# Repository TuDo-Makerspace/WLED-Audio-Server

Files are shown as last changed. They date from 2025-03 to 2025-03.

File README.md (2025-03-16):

# WLED Audio Server

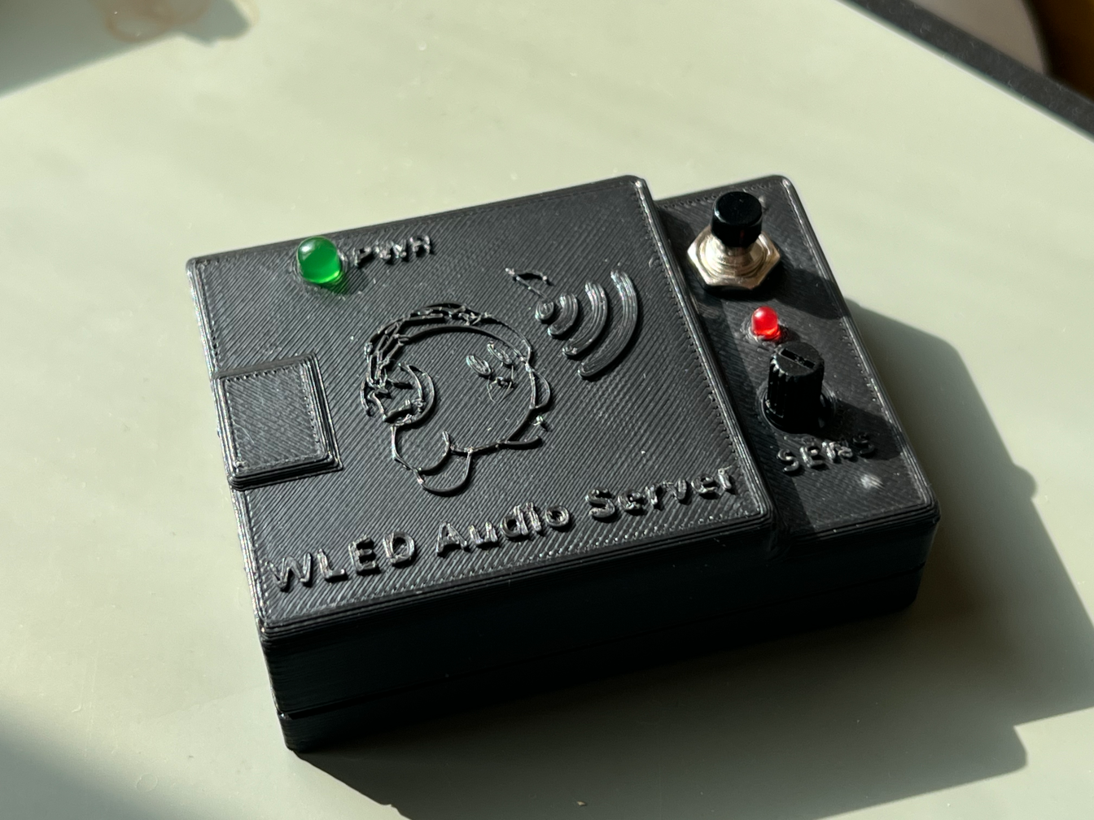
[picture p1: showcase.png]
WLED Audio Server


This compact device is designed to function as a WLED audio server. It analyzes 3.5mm audio input and synchronizes audio-reactive effects across multiple WLED devices using the "Sync" feature. I.e. this is just a "headless" WLED controller.

## Hardware

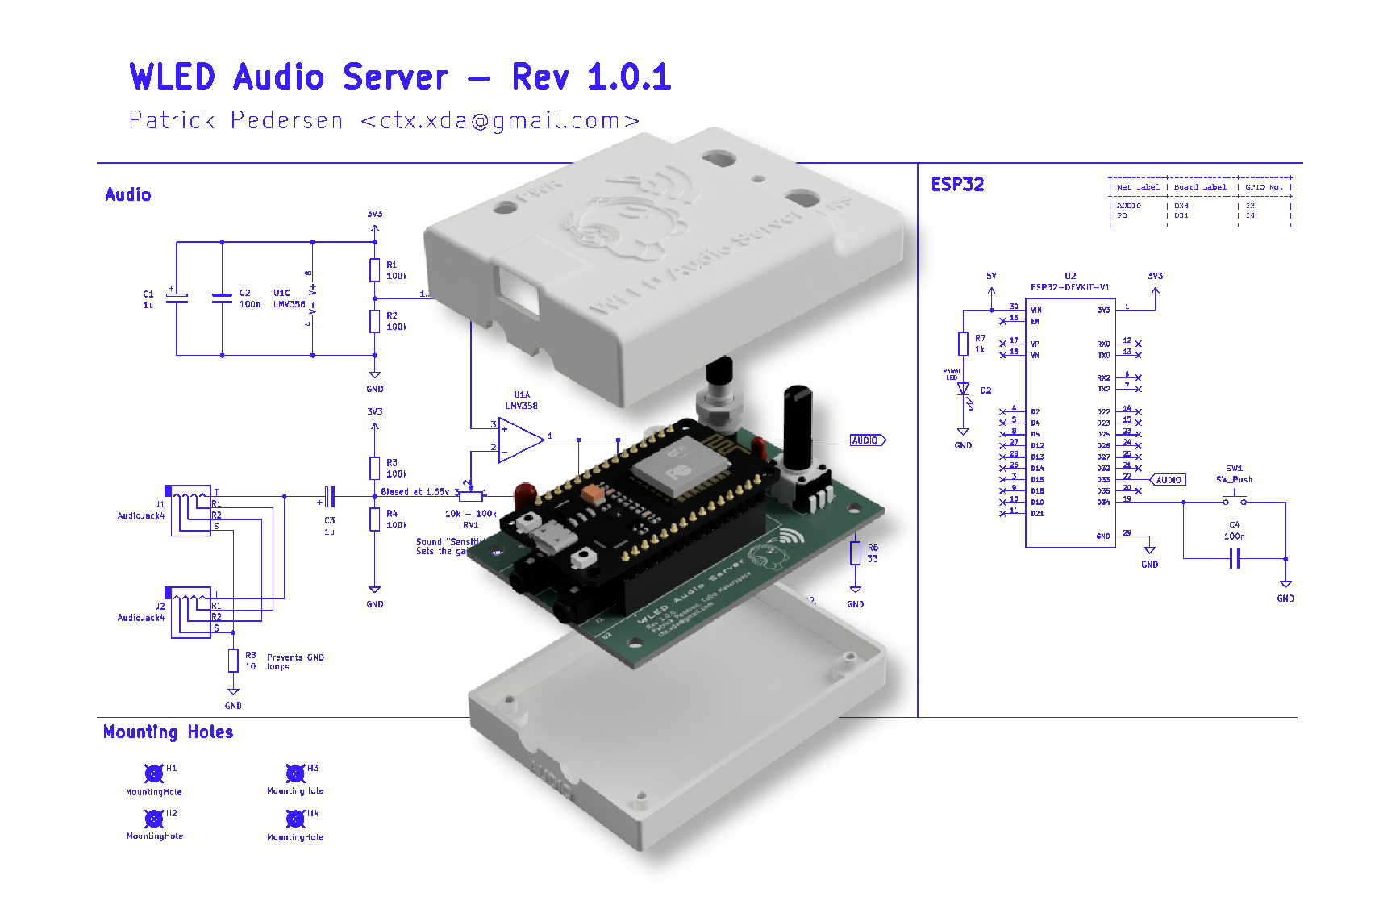
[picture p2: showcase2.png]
Hardware showcase


This device features two 3.5mm audio jacks: one for input and one for through-output (orientation is interchangable). This allows the server to be placed in-line between an audio source and a speaker system.

A potentiometer is used to adjust the gain of the audio input. This lets you amplify quieter signals or reduce the gain for louder ones to clipping. To help with this, a small red clipping LED is included.

Additionally, a push-button is provided, which can be assigned to a specific WLED action, such as changing the effect.

Finally, a power LED is included to indicate when the device is powered on.

The KiCAD files for the Schematic and PCB layout can be found in this repo.

## Firmware

For enhanced audio-reactive capabilities, it is highly recommended to use the **[MoonModules fork of WLED](https://mm.kno.wled.ge/)** on both the audio server and all connected WLED devices. This fork includes additional features and optimizations specifically designed for audio-reactive setups.

A [pre-configured firmware binary](WLED-MM_esp32_4MB_M_14.5.1-dev_preconfigured.bin) for the audio server is available in this repository for quick setup.

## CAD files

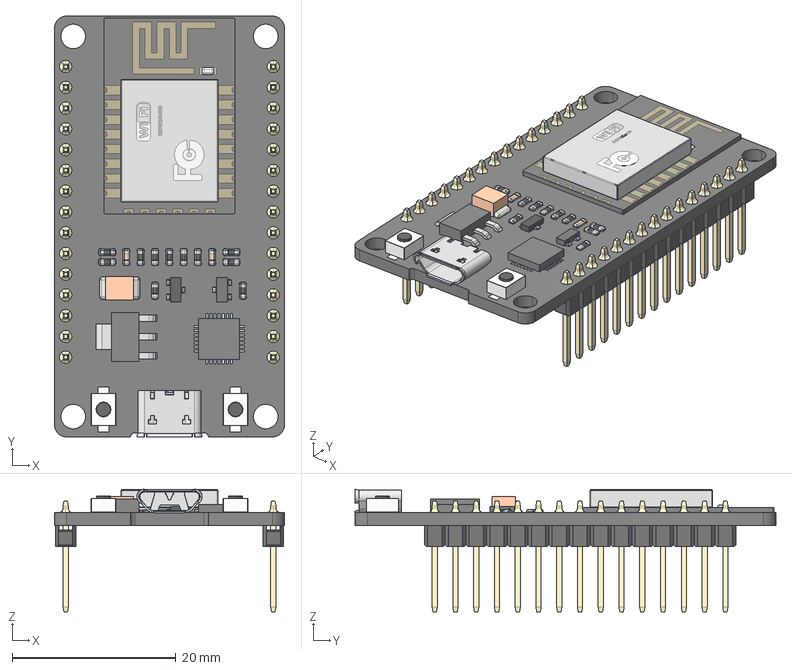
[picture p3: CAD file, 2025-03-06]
3d/esp32_dev_kit_v1_asm.stp
28.1 x 51.5 x 15.0 mm
PCB
PIN x 30
WIFI_CARD_2
RECTANGULARCHIP_2
MICROCHIP_2
TANCHIP_2
TRANSISTOR_3-LEG_2
RESISTOR1_2 x 11
RESISTOR2-32_2 x 2
TRANSISTOR_3-LEG2_2
BUTTONFLASH-13_2 x 2
BUTTONFLASH-14_2 x 2
USB_SOCKET_2

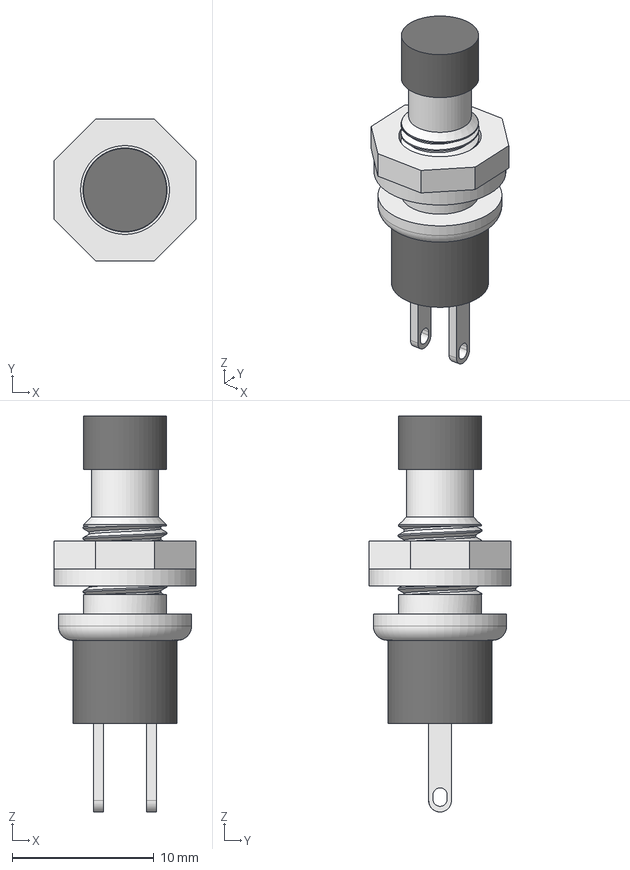
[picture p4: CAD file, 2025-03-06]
3d/Push Button.step
10.0 x 10.0 x 27.9 mm

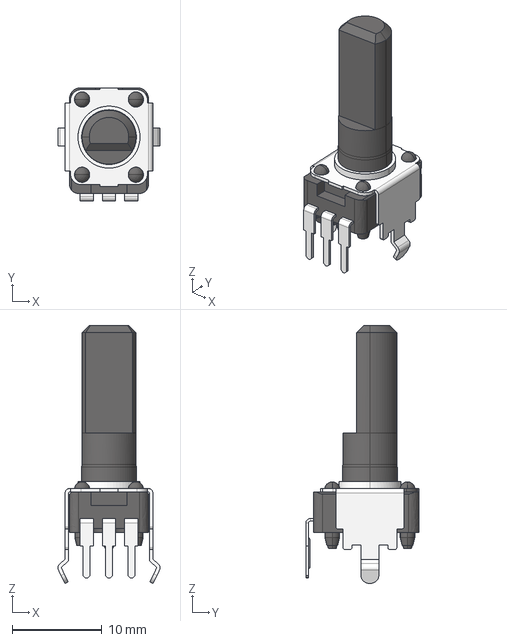
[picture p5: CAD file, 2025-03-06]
3d/RK09K1130AH1.STEP
11.4 x 12.7 x 28.8 mm

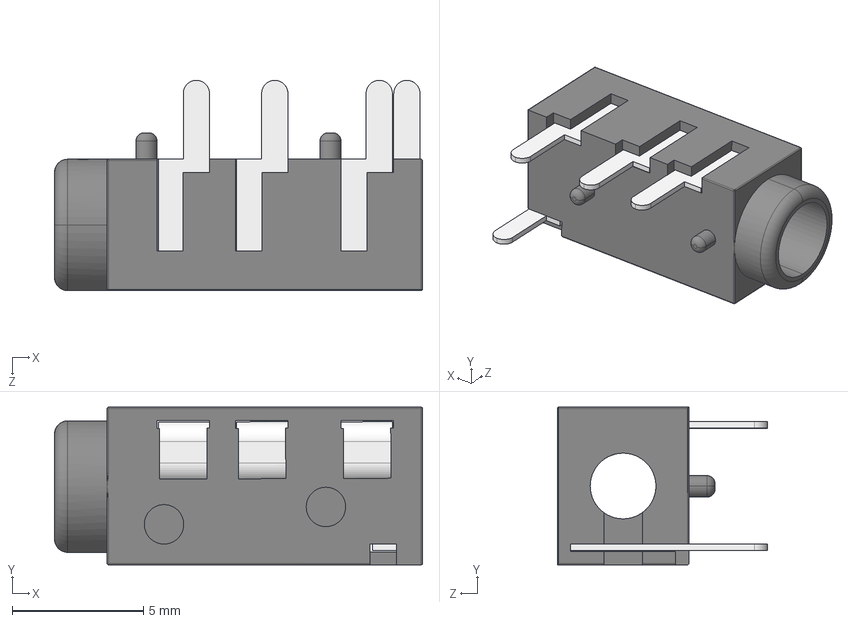
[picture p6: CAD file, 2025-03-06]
3d/PJ320A.STEP
14.0 x 6.00 x 8.00 mm
PJ320A
PJ320A-Pin x 3
PJ320A-Pin-B

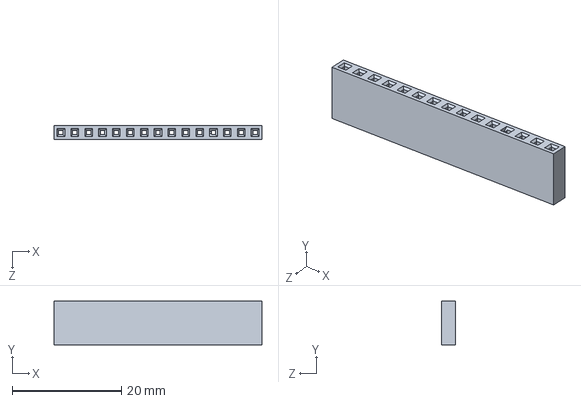
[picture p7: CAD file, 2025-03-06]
3d/Header_Female_single_15.STEP
38.1 x 8.00 x 2.50 mm

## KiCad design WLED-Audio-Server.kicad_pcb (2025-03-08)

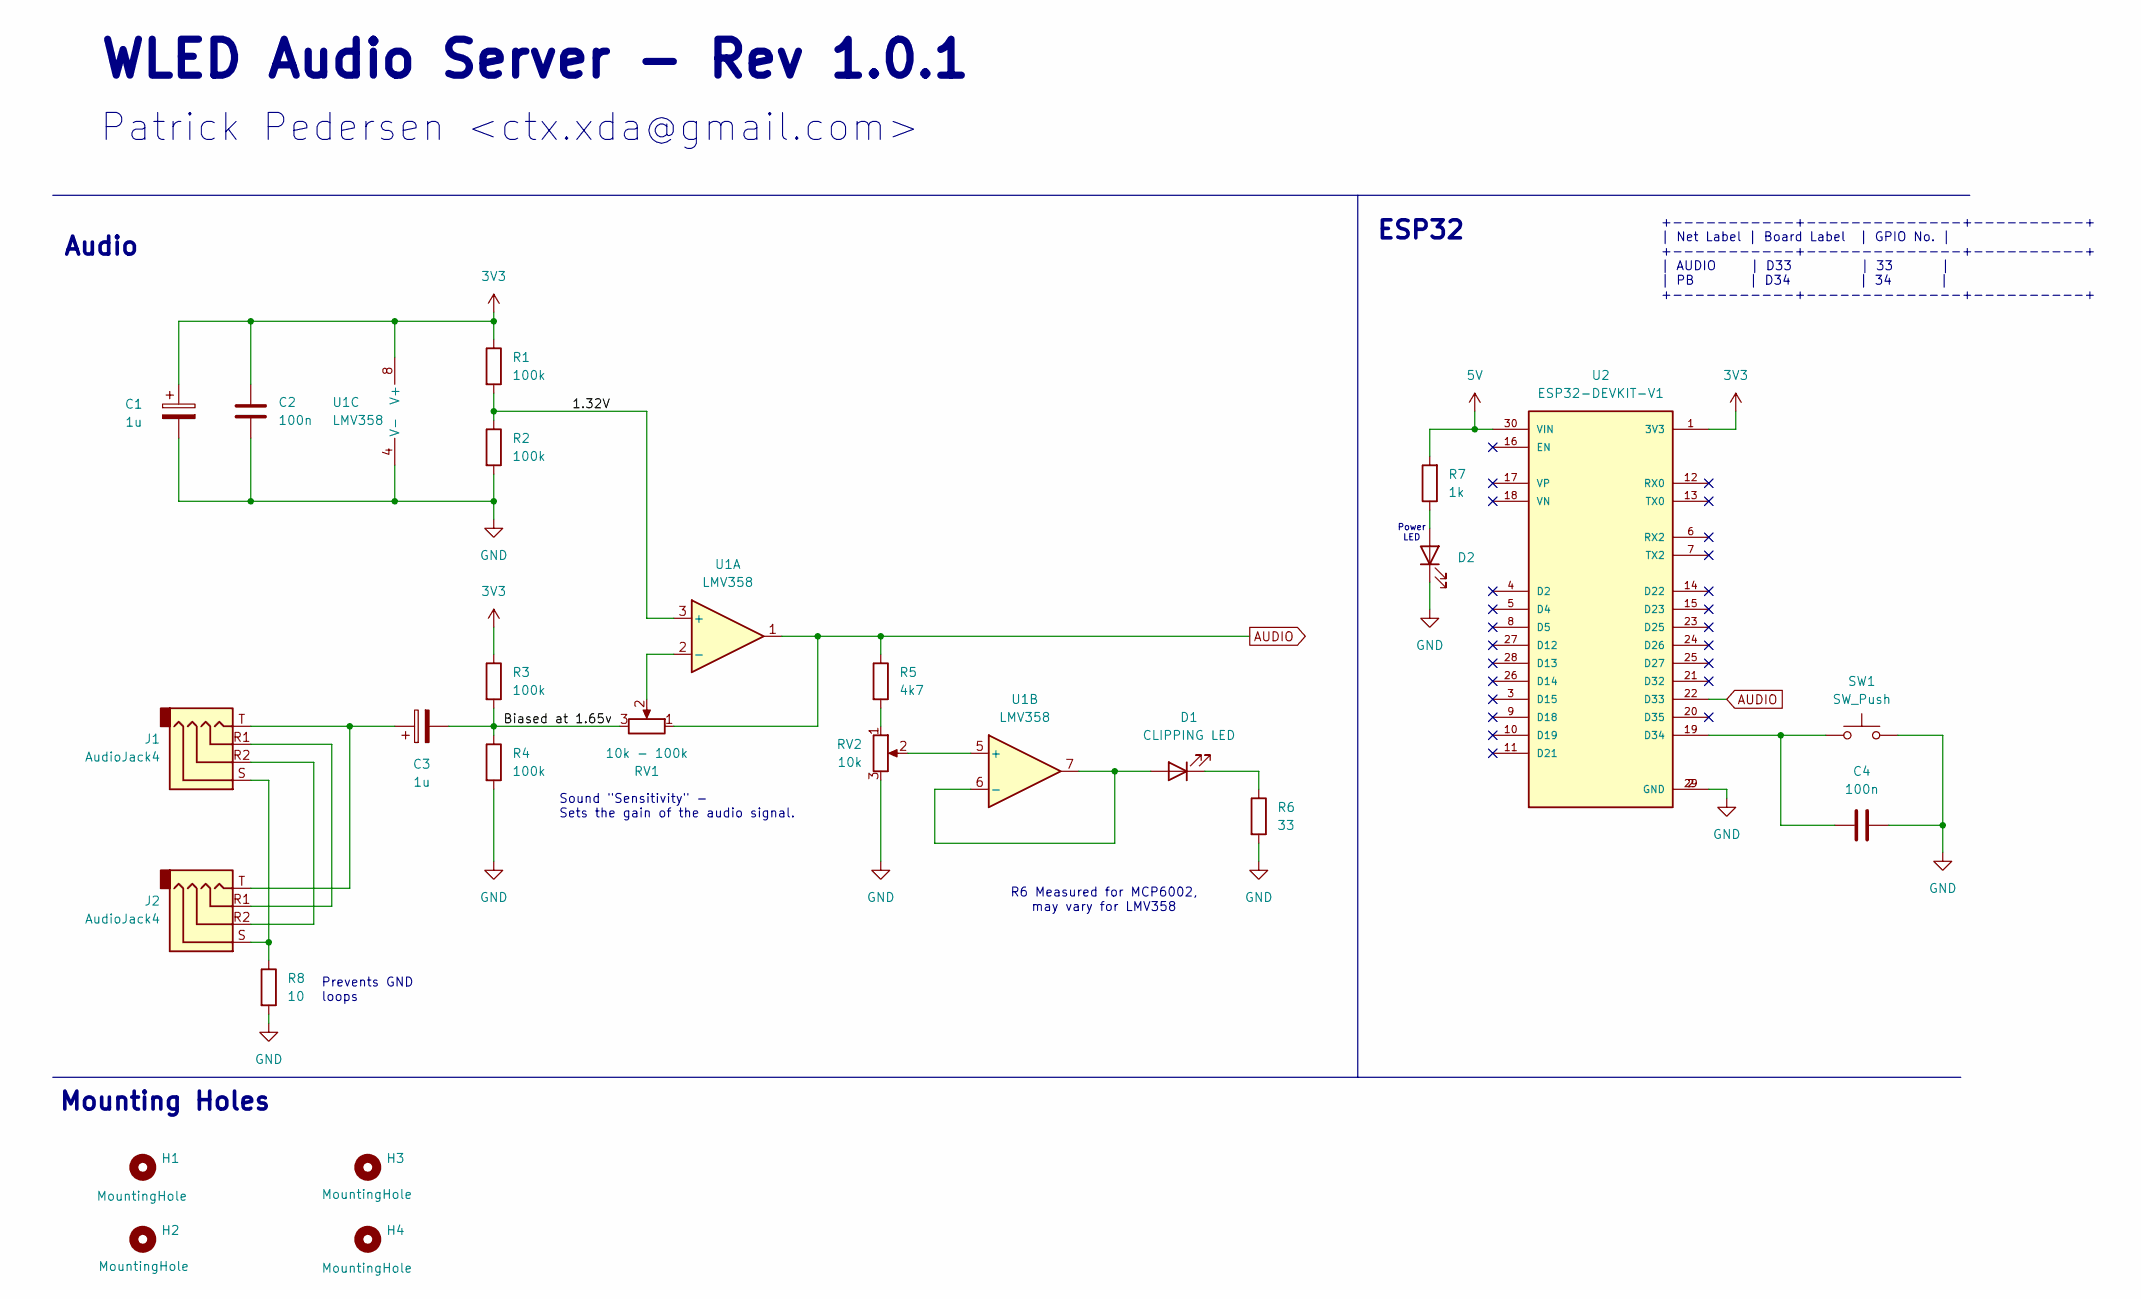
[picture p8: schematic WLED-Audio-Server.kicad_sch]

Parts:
C1, C3: 1u; CP_Radial_D4.0mm_P2.00mm
C2, C4: 100n; C_1206_3216Metric_Pad1.33x1.80mm_HandSolder
D1: CLIPPING LED; LED_D3.0mm
D2: LED; LED_D5.0mm
H1, H2, H3, H4: MountingHole; MountingHole_3.2mm_M3
J1, J2: AudioJack4; TRRS-PJ-320A
R1, R2, R3, R4: 100k; R_1206_3216Metric_Pad1.30x1.75mm_HandSolder
R5: 4k7; R_1206_3216Metric_Pad1.30x1.75mm_HandSolder
R6: 33; R_1206_3216Metric_Pad1.30x1.75mm_HandSolder
R7: 1k; R_1206_3216Metric_Pad1.30x1.75mm_HandSolder
R8: 10; R_1206_3216Metric_Pad1.30x1.75mm_HandSolder
RV1: 10k - 100k; Potentiometer_RV09
RV2: 10k; Potentiometer_Runtron_RM-065_Vertical
SW1: SW_Push; SW_Push_ThroughHole_2Pin_7mm
U1: LMV358; SOIC-8_3.9x4.9mm_P1.27mm
U2: ESP32-DEVKIT-V1; MODULE_ESP32_DEVKIT_V1; PARTREV N/A

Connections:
3V3: C1.1, C2.2, R1.1, R3.1, U1.8 (V+), U2.1 (3V3)
5V: R7.2, U2.30 (VIN)
/1.32V: R1.2, R2.1, U1.3 (+)
/Biased at 1.65v: C3.2, R3.2, R4.1, RV1.3
AUDIO: R5.1, RV1.1, U1.1, U2.22 (D33)
GND: C1.2, C2.1, C4.2, D2.1 (K), R2.2, R4.2, R6.2, R8.2, RV2.3, SW1.2, U1.4 (V-), U2.2 (GND), U2.29 (GND)
unnamed: C3.1, J1.T, J2.T
unnamed: D1.2 (A), U1.6 (-), U1.7
unnamed: D1.1 (K), R6.1
unnamed: D2.2 (A), R7.1
unnamed: J1.R1, J2.R1
unnamed: J1.R2, J2.R2
unnamed: J1.S, J2.S, R8.1
unnamed: R5.2, RV2.1
unnamed: RV1.2, U1.2 (-)
unnamed: RV2.2, U1.5 (+)
unnamed: C4.1, SW1.1, U2.19 (D34)

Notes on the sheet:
Patrick Pedersen <ctx.xda@gmail.com>
Audio
Mounting Holes
ESP32
Prevents GND loops
Sound "Sensitivity" - Sets the gain of the audio signal.
R6 Measured for MCP6002, may vary for LMV358
Power LED
+-----------+--------------+----------+ | Net Label | Board Label | GPIO No. | +-----------+--------------+----------+ | AUDIO | D33 | 33 | | PB | D34 | 34 | +-----------+--------------+----------+
WLED Audio Server - Rev 1.0.1

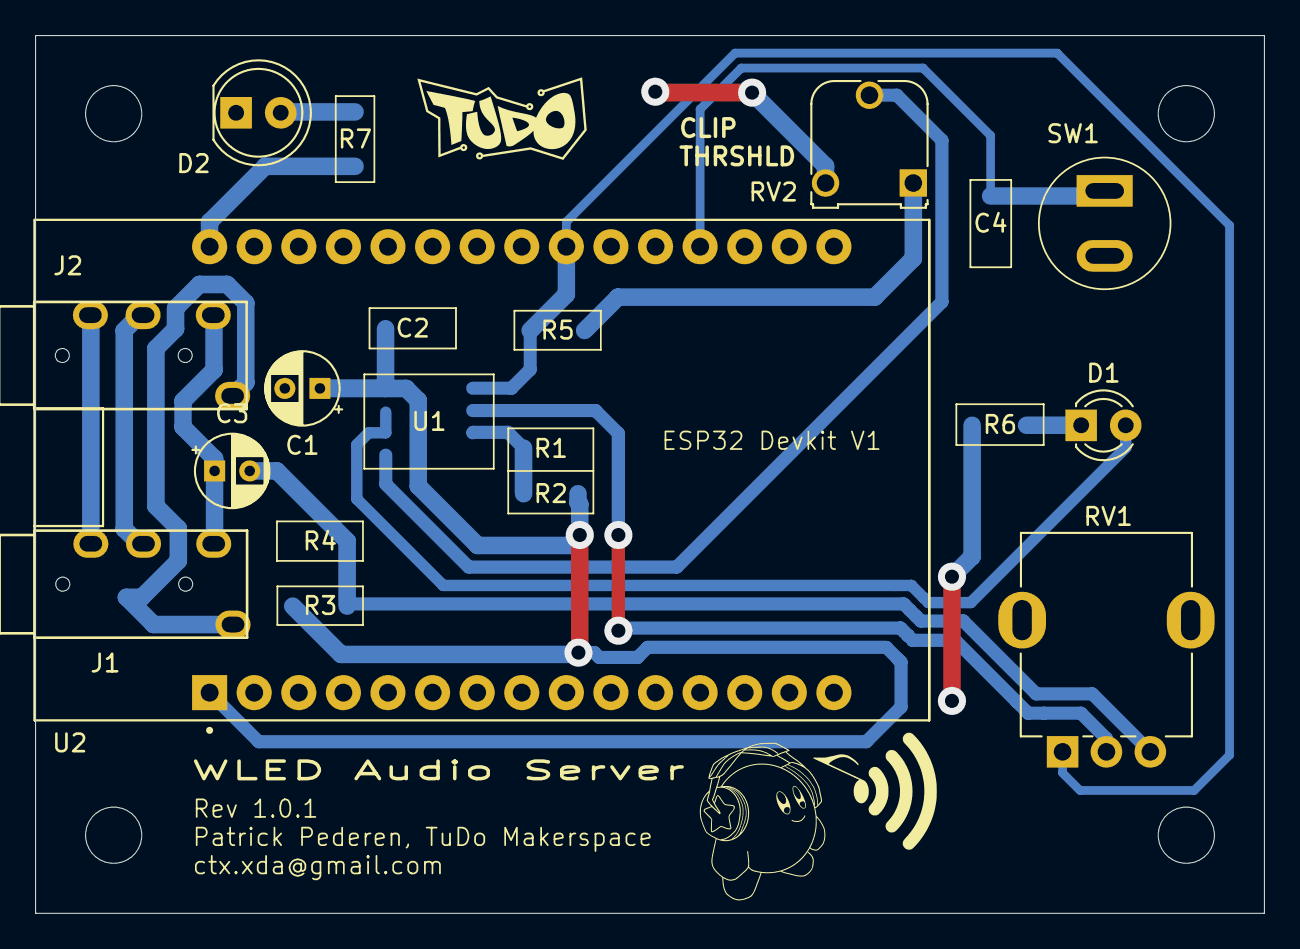
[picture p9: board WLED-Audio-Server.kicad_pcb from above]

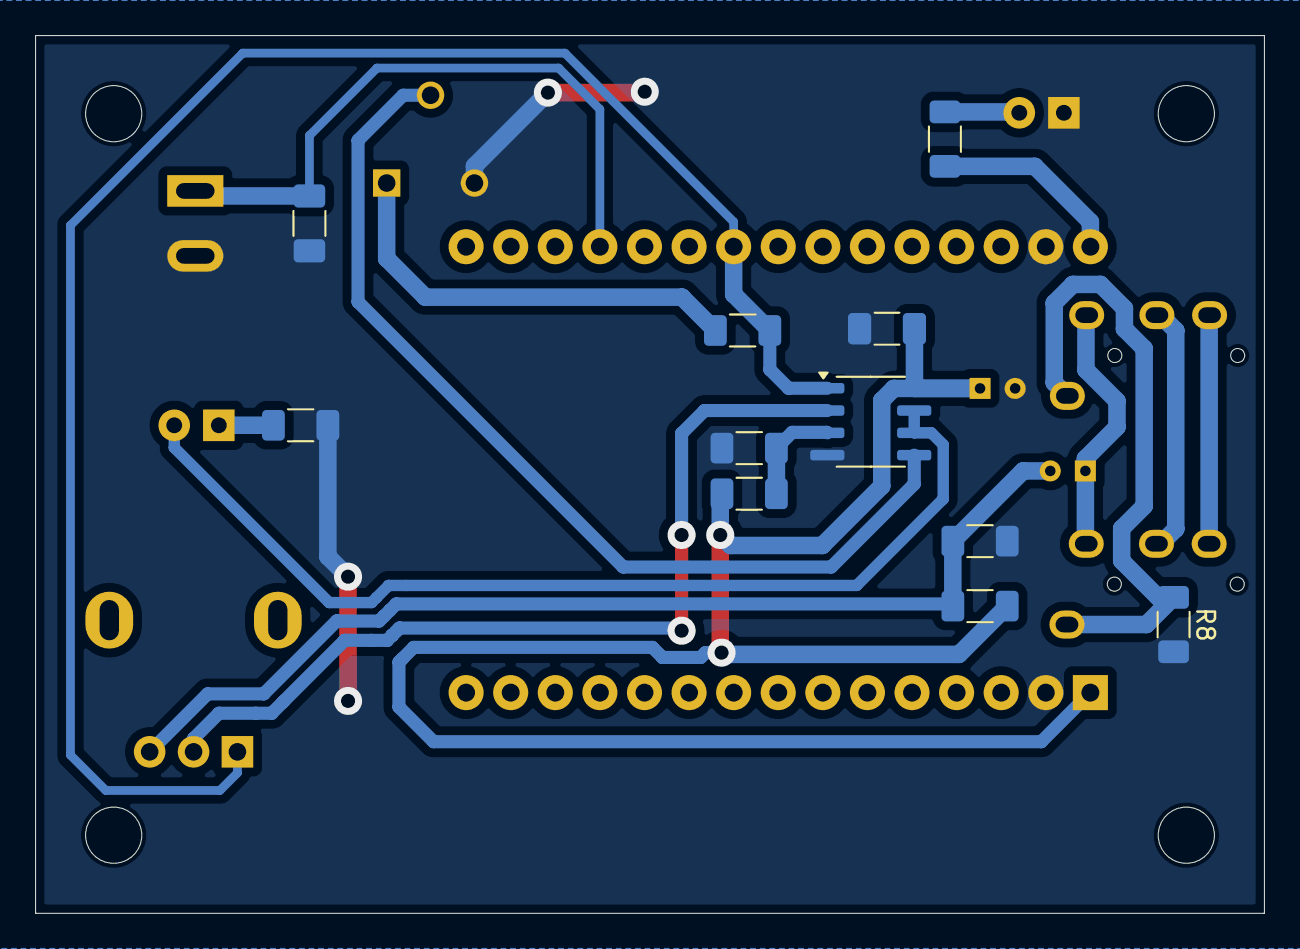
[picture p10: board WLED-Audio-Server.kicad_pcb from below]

Board: 2 copper layers, 70.0 x 50.0 mm, 25 parts (11 on the bottom side), 17 nets.

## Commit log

2025-03-06 Added 3d models
    [Header_Female_single_15.STEP, PJ320A.STEP, Push Button.step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]
2025-03-06 Re-aligned mounting holes
    [WLED-Audio-Server.kicad_pcb]
2025-03-08 Revision 1.0.1: Fixed potentiometer orientation + PB Pitch
    [WLED-Audio-Server.kicad_pcb, WLED-Audio-Server.kicad_sch]
